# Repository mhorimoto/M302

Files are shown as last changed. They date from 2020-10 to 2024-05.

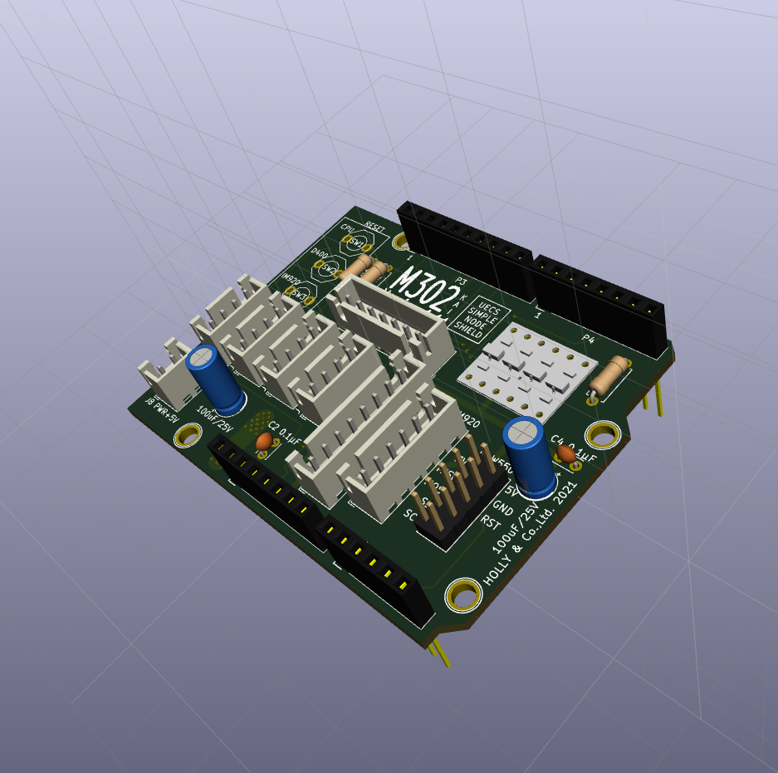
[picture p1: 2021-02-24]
M302kai-3d02.png

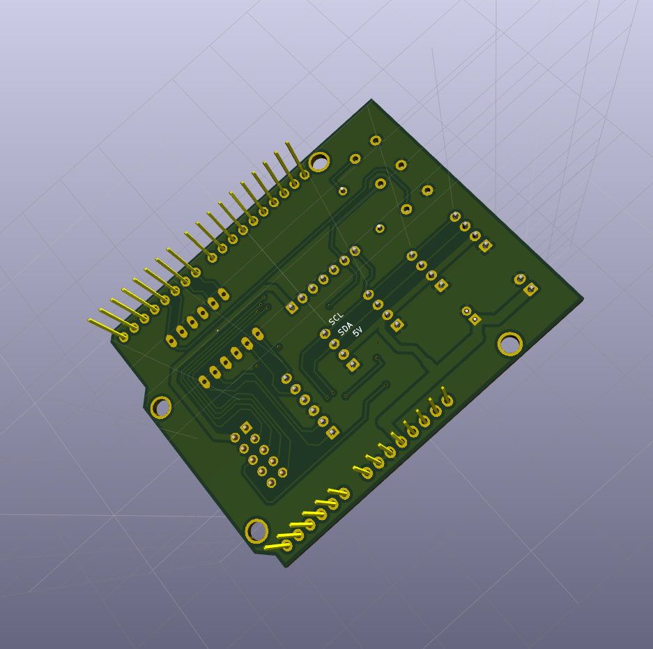
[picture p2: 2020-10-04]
M302-3d06.png

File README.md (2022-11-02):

M302 Arduino UECS SIMPLE NODE Shield 汎用簡易観測ノード
======================================================

# 概要

Arduino UNOのシールドとして UECS で農業環境計測で使用しやすい
センサ類の接続に特化した基板。

## 初版 (1.00)
  commit 2f4df36819d791f5551f218545c303c0058bd9ba
  * I2CとLANとIM920の接続インタフェースを持ったもの。

## 1.10
  * I2CとLANとADC入力とIM920の接続インタフェースを持ったもの。
  * 製作ワークショップなどで使用する用途も考慮。

# Interface仕様

 I2Cは5V仕様。IM920を接続するためだけにレベルコンバータを使用。

## I2C

 便宜的にシルク面にJ1〜J4は名前を記しているが、いずれもI2Cなので、以下のピン配置で同じく使用できる。なお、必要に応じてセンサ側でプルアップをするように。

 | PIN | 意味 |
 |-----|------|
 |  1  | GND  |
 |  2  | +5V  |
 |  3  | SDA  |
 |  4  | SCL  |

 J5はELT社のCO2センサD-400用のインタフェースである。基本的にI2Cであるが、リセット端子を個別に用意している。

 | PIN | 意味 |
 |-----|------|
 |  1  | +5V  |
 |  2  | N/C  |
 |  3  | GND  |
 |  4  | SDA  |
 |  5  | N/C  |
 |  6  | RST  |
 |  7  | SCL  |

## アナログ入力

Arduino UNOの10bits A/Dコンバータ(以降、ADC)を手軽に使用するために4chのコネクタをJ9(ANALOG-IN)として用意している。

 | PIN | 意味 |
 |-----|------|
 |  1  | Ch1  |
 |  2  | GND  |
 |  3  | Ch2  |
 |  4  | GND  |
 |  5  | Ch3  |
 |  6  | GND  |
 |  7  | Ch4  |
 |  8  | GND  |

## IM920接続インタフェース

920MHz伝送用無線通信モジュールIM920を接続するためのシリアルインタフェースを用意している。IM920が3.3V仕様なのでレベルコンバータを実装する。(IM920を使用しない場合にはレベルコンバータは不要)

 | PIN |   意味   |
 |-----|----------|
 |  1  | RESET    |
 |  2  | BUSY     |
 |  3  | GND      |
 |  4  | +3.3V    |
 |  5  | IM920 TX |
 |  6  | IM920 RX |

## LANインタフェース

W5500で一般的に販売されているものが接続出来るように用意している。

 | PIN | 意味  |
 |-----|-------|
 |  1  | +3.3V |
 |  2  | +5V   |
 |  3  | MISO  |
 |  4  | GND   |
 |  5  | MOSI  |
 |  6  | RESET |
 |  7  | SS    |
 |  8  | N/C   |
 |  9  | SCLK  |
 | 10  | N/C   |

# プログラム

スマ農塾に使用したプログラムは別途githubに登録してある。

''git@github.com:mhorimoto/smanou01.git''

それ以外のプログラムは、以下の通り。

## TK01

スマ農塾向けのサンプルプログラムで前述のものよりも古いバージョン

## TPM302K

M302Kの基板の試験をおこなうための試験プログラム。

## TPM302K-NIC

M302KのNIC(W5500)を動作させる試験プログラム

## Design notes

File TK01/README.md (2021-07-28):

スマート農業塾 UECS NODE トレーニングキット01
===========================================

M302KにSHT3xを接続して温度湿度計測を行い、結果をUECS電文で送信する装置。

- Version: V042
- Release: 29-Jul-2021
- Develop: HOLLY&Co.,Ltd.

## 必要なH/W

- Arduino UNO R3 互換機上等。ピン位置など物理形状は本家と同じにする
- M302K HOLLY製シールド基板
- SHT-31 温度湿度センサ
- W5500 NIC
- I2C I/F LCD 1602 (16桁2行)
- AC100/220V to DC5V/1.5A 電源
- プッシュスイッチ
- 電源用トグルスイッチ

## M302Kとの配線

M302KはArduino UNOのシールドとして接続する。

これから書く

## ソフトウェアのインストール

### EEPROMの初期値

この初期値設定は、Arduino UNO 単体で実行する。

MACアドレスやUECSID,ROOM,REGIONなどの位置情報の初期値を設定する。

このプログラムは、lowcore サブディレクトリの配下にある。この lowcore.ino をArduino UNOに最初にインストールして初期値を作成する。  
詳細は、 [lowcore/README.md](lowcore/README.md) を参照の事。

また、初期化の内容は、 [EEPROM_MAP.md](EEPROM_MAP.md) に記されている。

### 主プログラムのインストール

主プログラムは、main サブディレクトリの配下に全て含まれている。
それを Arduino IDE などでコンパイルしてCPUにupload(install)する。

## 使い方

使い方は、取扱説明書を [main/MANUAL.md](main/MANUAL.md) に記すので、そちらを参照する。
まだ書かれていない。

## 著作権

This software is released under the MIT License, see [LICENSE.txt](LICENSE.txt).  
(このソフトウェアは、MITライセンスのもとで公開されている。[LICENSE-ja.txt](LICENSE-ja.txt)を見よ。)

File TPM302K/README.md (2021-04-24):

TPM302K
=======
M302K用検査プログラム

M302Kの基板製造上、接続の正当性を確認する検査プログラム

ArduinoのI/OピンをOutputにして順序立てて接続ピンを点滅させることで、LEDの点滅を見つつ接続を確認する。

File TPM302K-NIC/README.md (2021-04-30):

TPM302K
=======
M302K用検査プログラム W5500 テストプログラム

M302Kの基板製造上、接続の正当性を確認する検査プログラム

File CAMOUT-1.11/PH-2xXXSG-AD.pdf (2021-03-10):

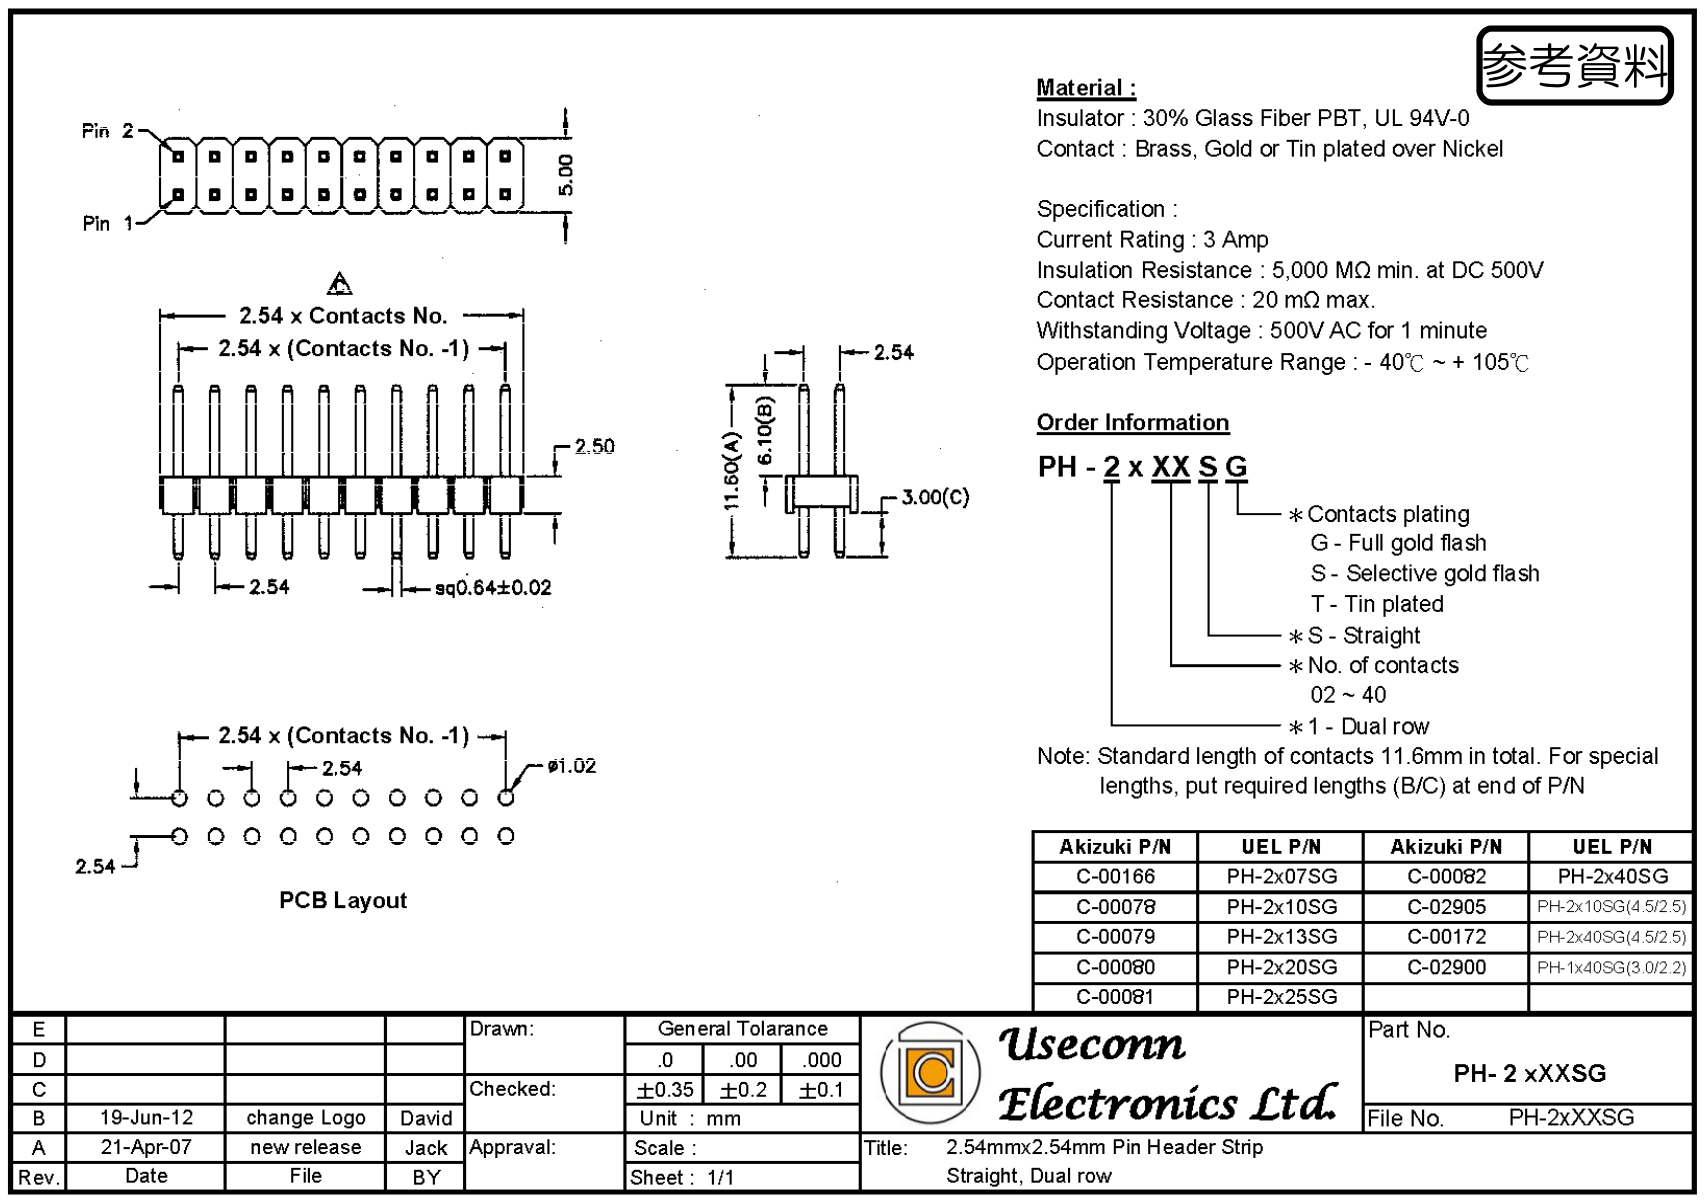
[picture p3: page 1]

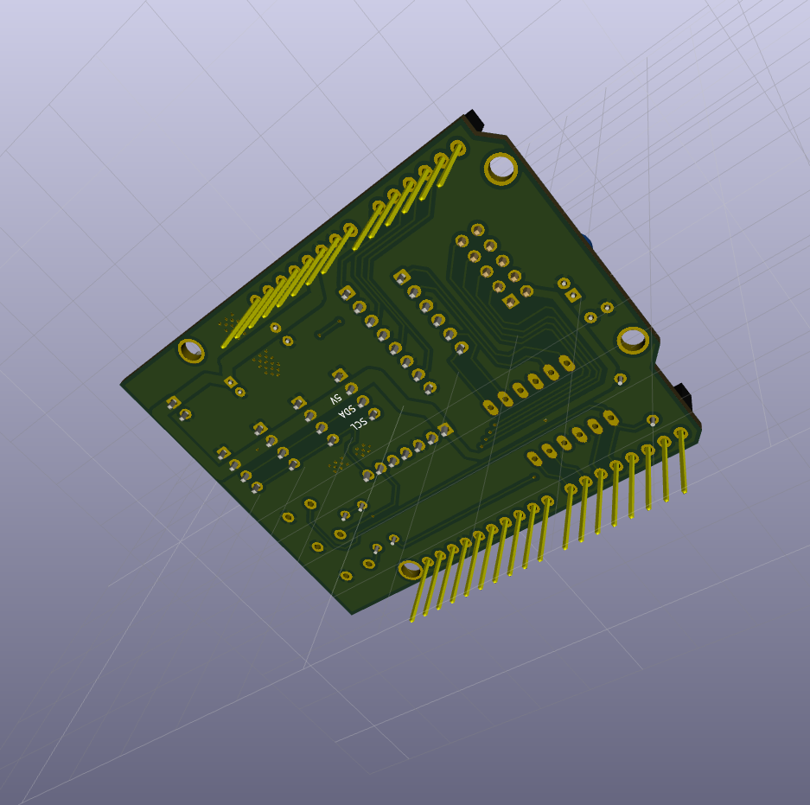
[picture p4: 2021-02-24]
M302kai-3d03.png

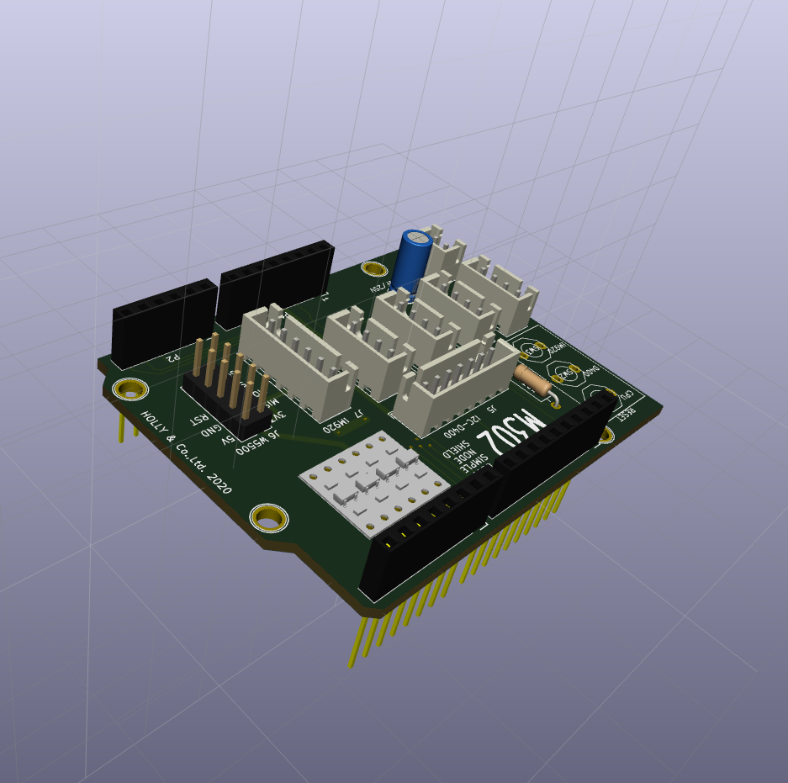
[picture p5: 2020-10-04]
M302-3d07.png

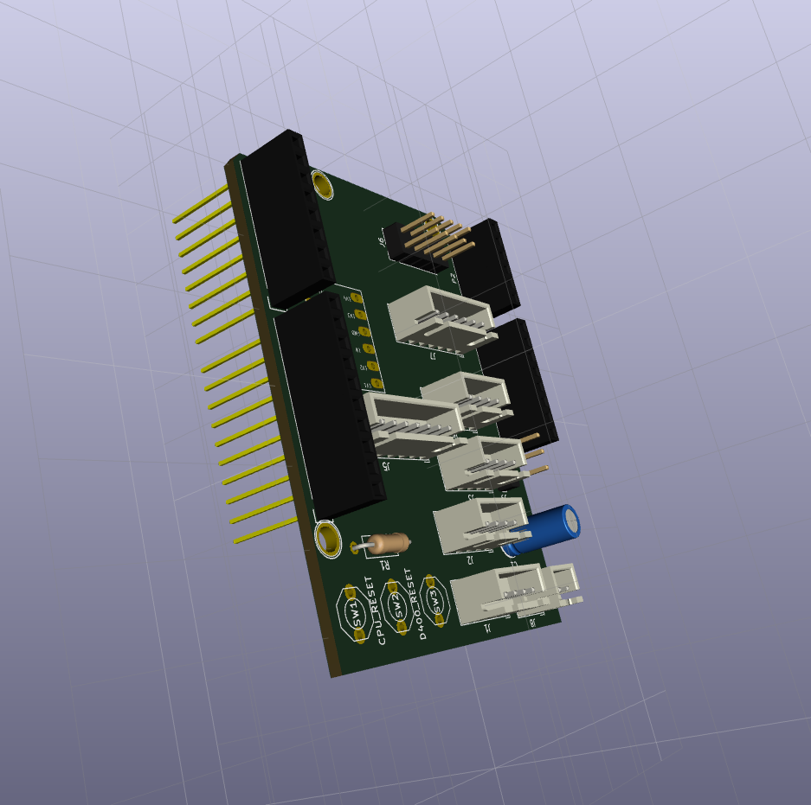
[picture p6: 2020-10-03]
M302-3d02.png

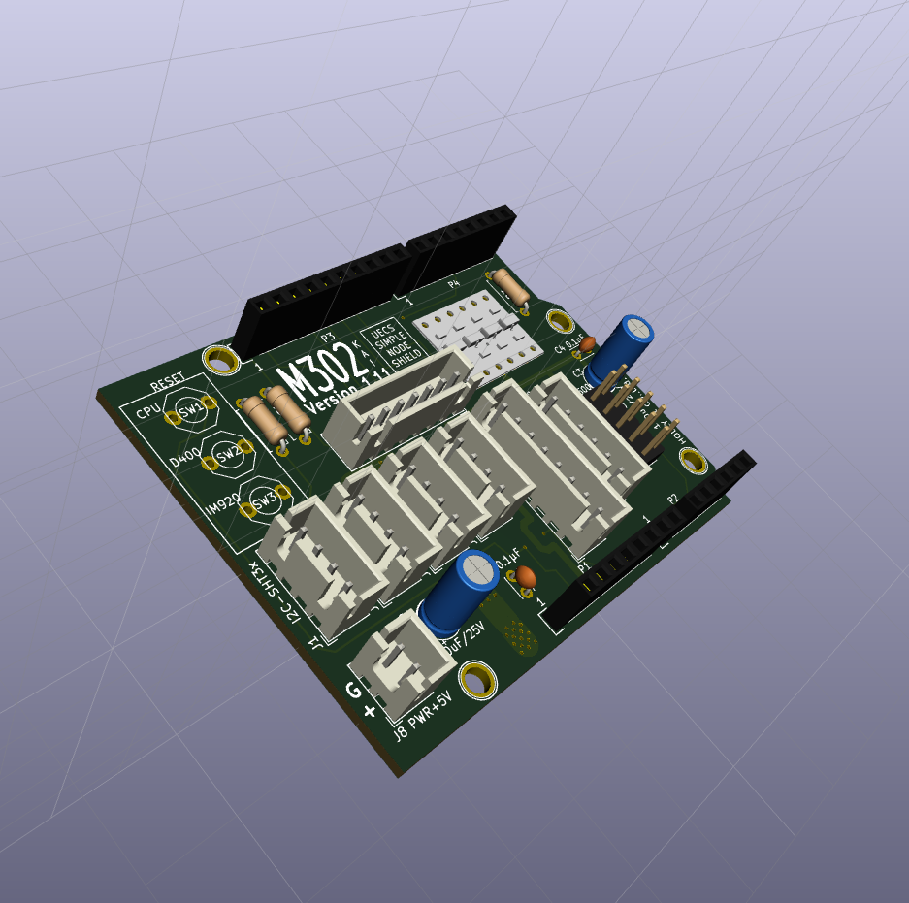
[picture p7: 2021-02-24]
M302kai-3d01.png

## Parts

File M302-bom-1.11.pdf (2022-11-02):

## M302 PARTS LIST

品名 Name | 部品番号 Designator | 個数 Quanity | 値 Value | 秋月品番 | 説明 Description | 部品メーカ Manufacturer | メーカ品番 Manufacturer Part Number
抵抗 | R1 R2 R3 | 3 10kΩ | | R-16103 | | SHIH HAO Electronics | RD16S 10K
コンデンサ | C1 C3 | 2 100uF/25V | | P-03122 | | Rubycon | 25PK100MEFC5X11
コンデンサ | C2 C4 | 2 0.1uF | | P-00090 | | muRata | RPEF11H104Z2P1A01B
XHコネクタ | J1 J2 J3 J4 | 4 | ベース付ポスト・トップ型4P | C-12249 | I2C I/F用 | JST | B4B-XH-A(LF)(SN)
XHコネクタ | J5 | 1 | ベース付ポスト・トップ型7P | C-12252 | D400 I/F用 | JST | B7B-XH-A(LF)(SN)
Pin Header | J6 | 1 | 2.54mmピッチピンヘッダ 2x5 | C-13635 | W5500 I/F用 | Useconn Electronics | PH2X5SG
XHコネクタ | J7 | 1 | ベース付ポスト・トップ型6P | C-12251 | IM920 I/F用 | JST | B6B-XH-A(LF)(SN)
XHコネクタ | J8 | 1 | ベース付ポスト・トップ型2P | C-12247 | POWER用 | JST | B2B-XH-A(LF)(SN)
XHコネクタ | J9 | 1 | ベース付ポスト・トップ型8P | C-12253 | ADC用 | JST | B8B-XH-A(LF)(SN)
Arduino Pin Header | P1 P4 | 2 | ピンソケット 1x8 リード長 10mm | C-04046 | Arduino Long Pin | Useconn Electronics | FH105-1x8SG/RH
Arduino Pin Header | P2 | 1 | ピンソケット 1x6 リード長 10mm | C-04045 | Arduino Long Pin | Useconn Electronics | FH105-1x6SG/RH
Arduino Pin Header | P3 | 1 | ピンソケット 1x10 リード長 10mm | C-07199 | Arduino Long Pin | Useconn Electronics | FH105-1x10SG
タクトスイッチ | SW1 | 1 | タクトスイッチ・1回路1接点・赤 | P-08079 | CPU RESET | Zhejiang Jianfu Electronics | TVDT18-050CR-T
タクトスイッチ | SW2 SW3 | 2 | タクトスイッチ・1回路1接点・白 | P-08080 | I/O RESET | Zhejiang Jianfu Electronics | TVDT18-050CW-T
液晶表示器 | 外部パーツ | 1 LCD 16x2 I2C | | Amazon (https://www.amazon.co.jp/waves-1602-LCD%E6%B6%B2%E6%99%B6-%E3%83%A2%E3%82%B8%E3%83%A5%E3%83%BC%E3%83%AB-Arduino/dp/B07BJ5PW3R) | コネクタ別途 | Waves | LCD-1602-I2C-0X3F
XHハウジング | 外部パーツ | 2 | XHコネクタ ハウジング 4P | C-12257 | LCD,SHT用 | JST | XHP-4
コネクタ用ハウジング | 外部パーツ | 1 | コネクタ用ハウジング4P | C-12153 | LCD用 | Neltron Industrial | 2226A-04
XHコンタクト | 外部パーツ | 1 | XHハウジング用コンタクト入数100個 | C-12265 | | | SXH-001T-P0.6
ケーブル用コネクタ | 外部パーツ | 2 | コンタクト部品入数10個 | C-12160 | | Neltron Industrial | 2226TG
LANモジュール | 外部パーツ | 1 W5500 | | Amazon (https://www.amazon.co.jp/W5500%E3%82%A4%E3%83%BC%E3%82%B5%E3%83%8D%E3%83%83%E3%83%88%E3%82%B7%E3%83%BC%E3%83%AB%E3%83%89lan%E3%83%8D%E3%83%83%E3%83%88%E3%83%A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) | コネクタ別途 | Paialu
コネクタ用ハウジング | 外部パーツ | 2 2x5 | | C-12437 | LANモジュール用 | Chang Enn Co., Ltd. | 254AH-D10
温度湿度センサ | 外部パーツ | 1 SHT35 | | K-15654 | コネクタ別途
コネクタ用ハウジング | 外部パーツ | 1 | コネクタ用ハウジング5P | C-12154 | SHT35用 | Neltron Industrial | 2226A-05
配線用リード線 | 外部パーツ | 適宜 | AWG-28
Arduino UNO R3 | 外部パーツ | 1 Arduino UNO R3 | | | CPU
LCD URL | https://onl.sc/UfVgae6
W5500 URL | https://onl.sc/F9rLdia

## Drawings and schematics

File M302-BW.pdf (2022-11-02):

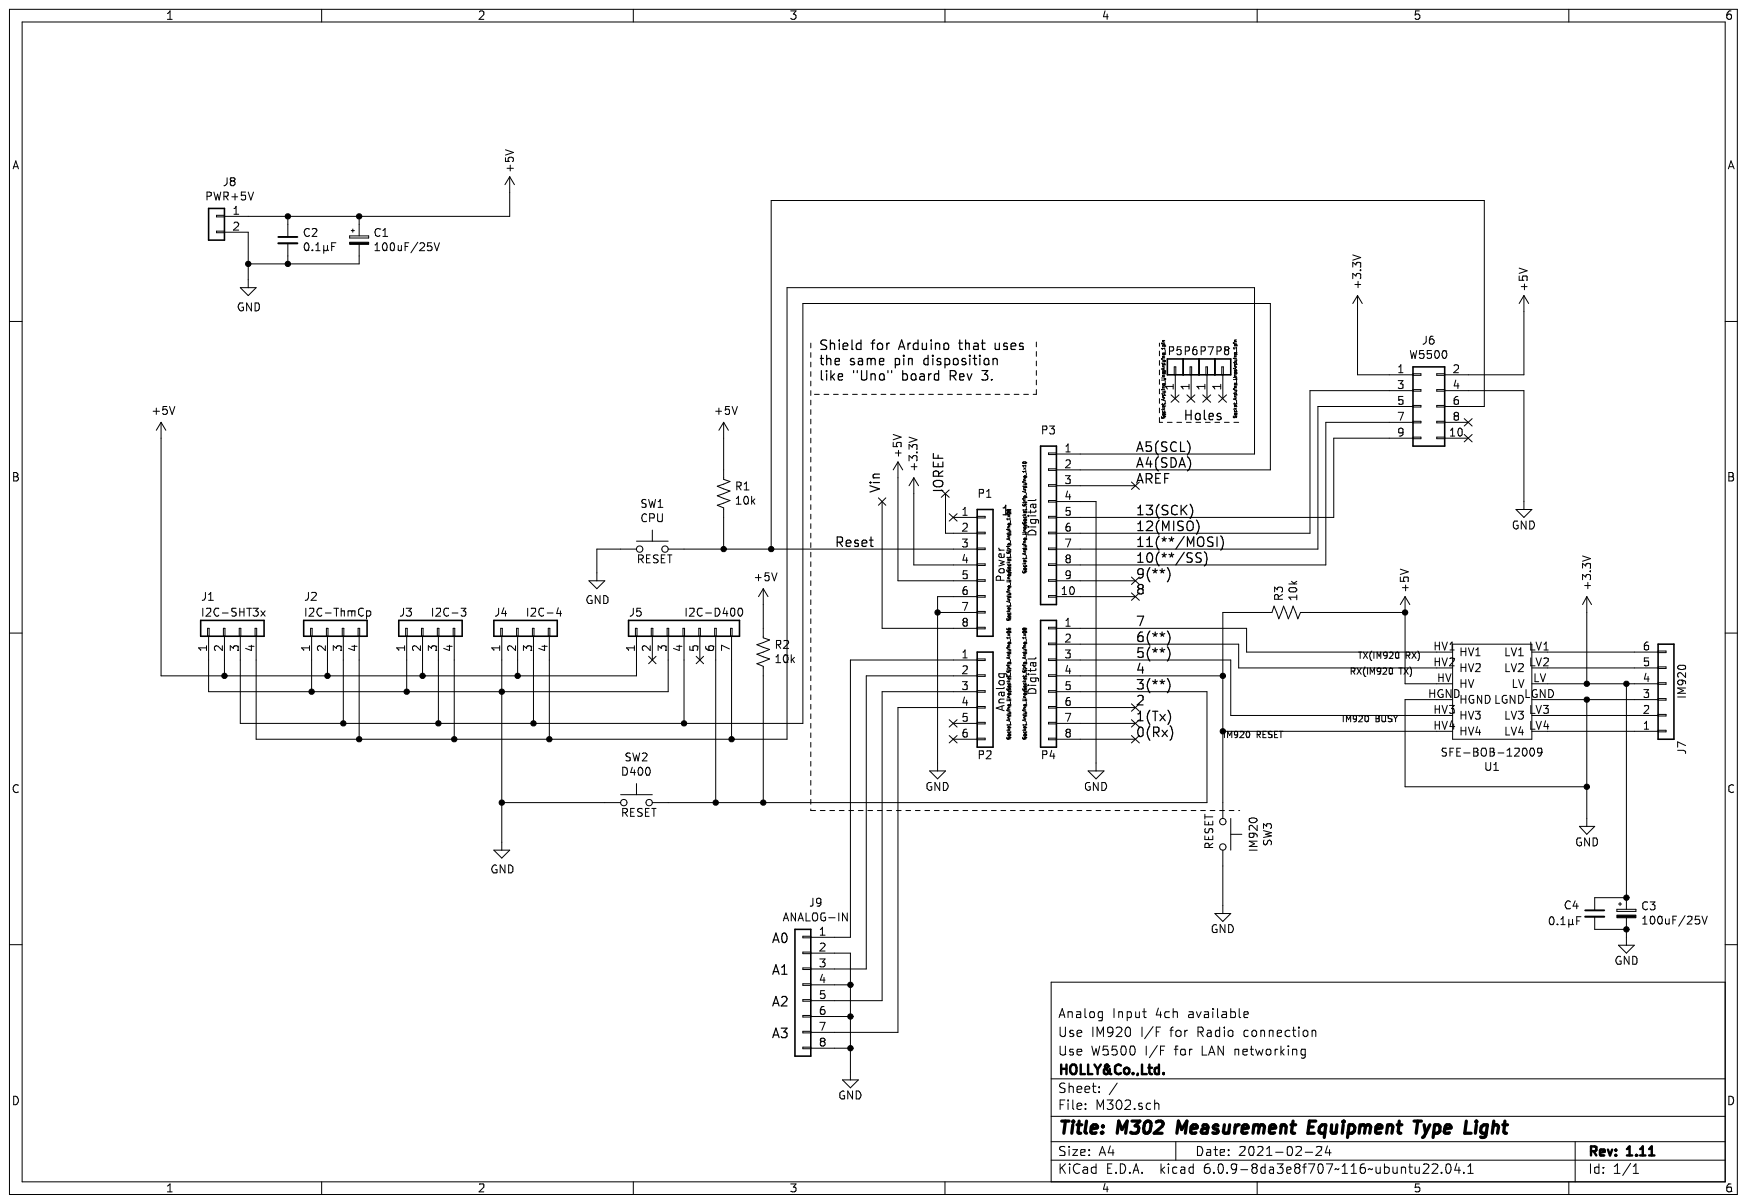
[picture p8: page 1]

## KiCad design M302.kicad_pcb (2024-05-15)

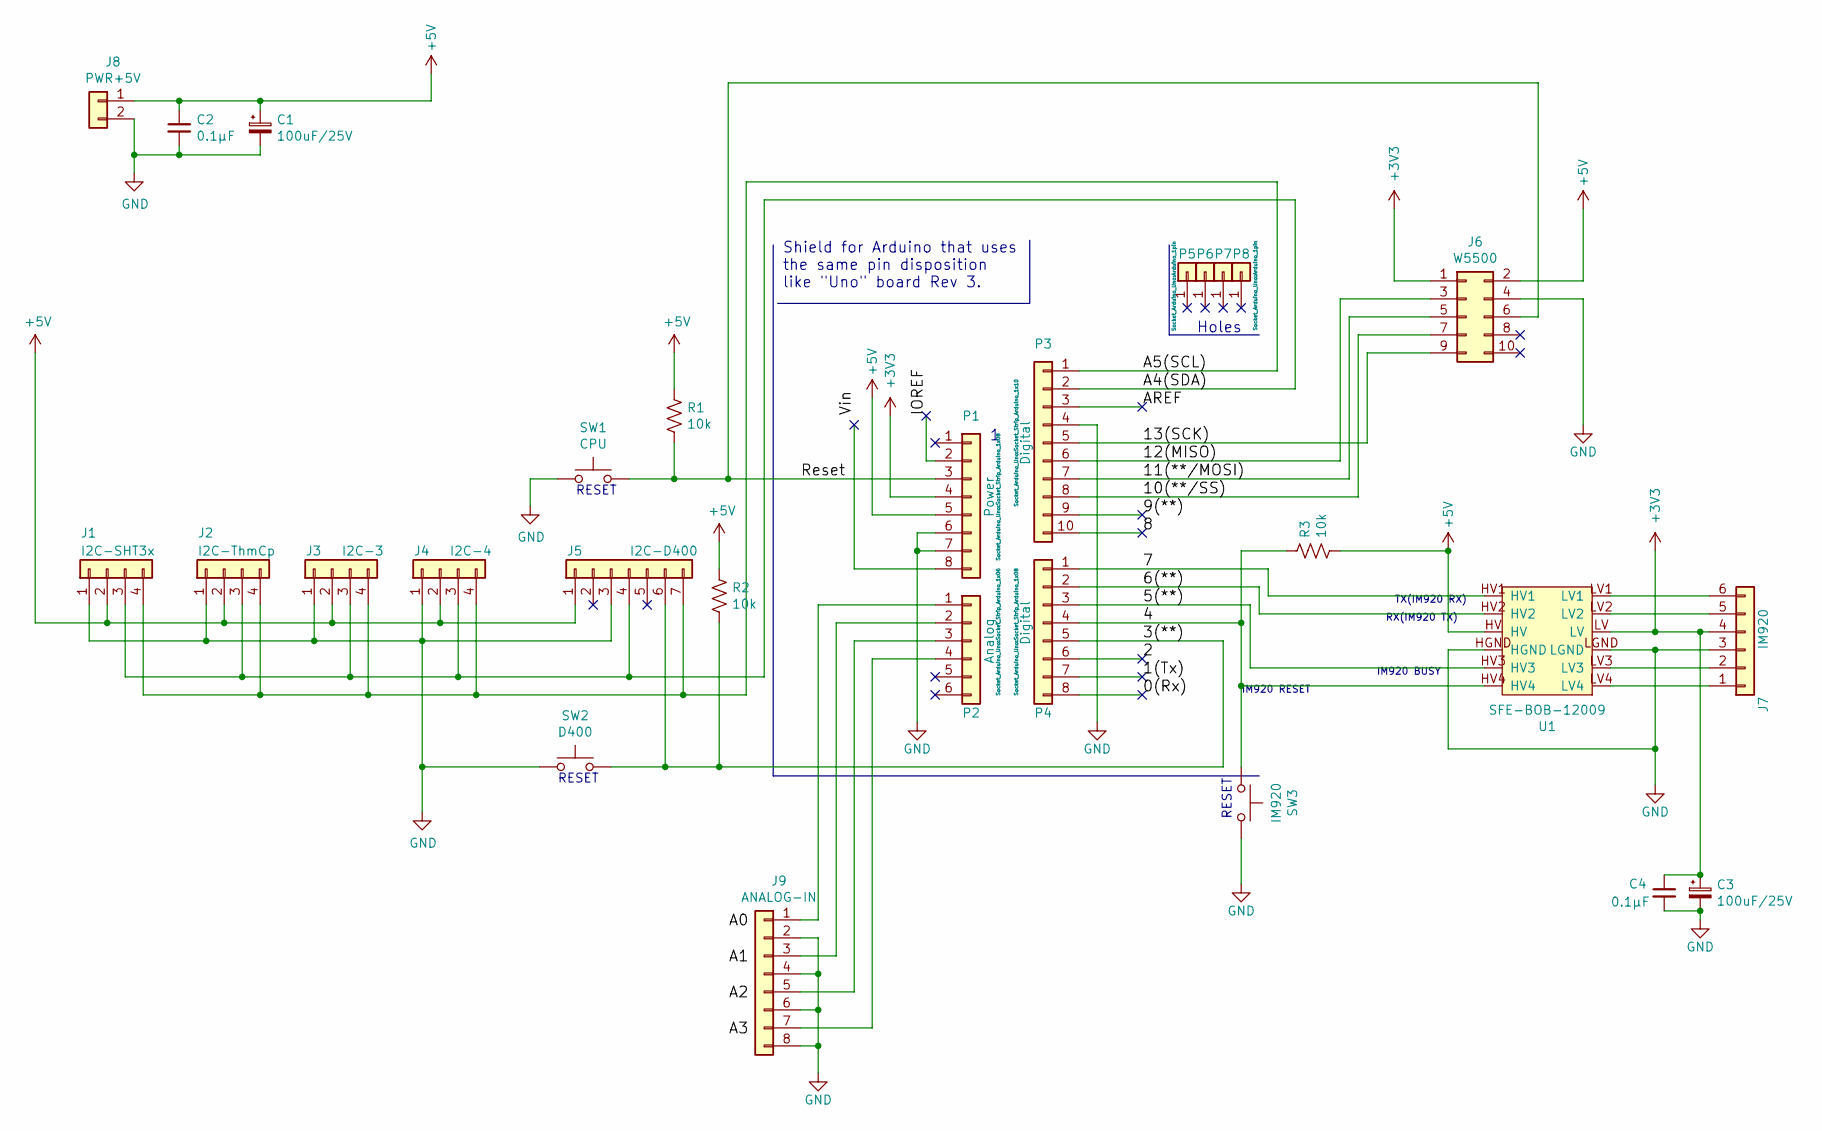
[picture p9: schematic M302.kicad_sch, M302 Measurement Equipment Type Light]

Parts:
C1, C3: 100uF/25V; CP_Radial_D5.0mm_P2.00mm
C2, C4: 0.1μF; C_Disc_D3.0mm_W2.0mm_P2.50mm
J1: I2C-SHT3x; JST_XH_B4B-XH-A_1x04_P2.50mm_Vertical
J2: I2C-ThmCp; JST_XH_B4B-XH-A_1x04_P2.50mm_Vertical
J3: I2C-3; JST_XH_B4B-XH-A_1x04_P2.50mm_Vertical
J4: I2C-4; JST_XH_B4B-XH-A_1x04_P2.50mm_Vertical
J5: I2C-D400; JST_XH_B7B-XH-A_1x07_P2.50mm_Vertical
J6: W5500; PinHeader_2x05_P2.54mm_Vertical
J7: IM920; JST_XH_B6B-XH-A_1x06_P2.50mm_Vertical
J8: PWR+5V; JST_XH_B2B-XH-A_1x02_P2.50mm_Vertical
J9: ANALOG-IN; JST_XH_B8B-XH-A_1x08_P2.50mm_Vertical
P1: Power; Socket_Strip_Arduino_1x08
P2: Analog; Socket_Strip_Arduino_1x06
P3: Digital; Socket_Strip_Arduino_1x10
P4: Digital; Socket_Strip_Arduino_1x08
P5, P6, P7, P8: CONN_01X01; Arduino_1pin
R1, R2, R3: 10k; R_Axial_DIN0207_L6.3mm_D2.5mm_P7.62mm_Horizontal
SW1: CPU; TVDT18-050
SW2: D400; TVDT18-050
SW3: IM920; TVDT18-050
U1: SFE-BOB-12009

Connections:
+3V3: C3.1, C4.1, J6.1, J7.4, P1.4, U1.LV
+5V: C1.1, C2.1, J1.2, J2.2, J3.2, J4.2, J5.1, J6.2, J8.1, P1.5, R1.1, R2.1, R3.2, U1.HV
/0(Rx): P4.8
/1(Tx): P4.7
/2: P4.6
/3(**): J5.6, P4.5, R2.2, SW2.2
/4: P4.4, R3.1, SW3.1, U1.HV4
/5(**): P4.3, U1.HV3
/6(**): P4.2, U1.HV2
/7: P4.1, U1.HV1
/8: P3.10
/9(**): P3.9
/10(**/SS): J6.7, P3.8
/11(**/MOSI): J6.5, P3.7
/12(MISO): J6.3, P3.6
/13(SCK): J6.9, P3.5
/A4(SDA): J1.3, J2.3, J3.3, J4.3, J5.4, P3.2
/A5(SCL): J1.4, J2.4, J3.4, J4.4, J5.7, P3.1
/AREF: P3.3
/IOREF: P1.2
/Reset: J6.6, P1.3, R1.2, SW1.2
GND: C1.2, C2.2, C3.2, C4.2, J1.1, J2.1, J3.1, J4.1, J5.3, J6.4, J7.3, J8.2, J9.2, J9.4, J9.6, J9.8, P1.6, P1.7, P3.4, SW1.1, SW2.1, SW3.2, U1.HGND, U1.LGND
unnamed: J7.1, U1.LV4
unnamed: J7.2, U1.LV3
unnamed: J7.5, U1.LV2
unnamed: J7.6, U1.LV1
unnamed: J9.1, P2.1
unnamed: J9.3, P2.2
unnamed: J9.5, P2.3
unnamed: J9.7, P2.4

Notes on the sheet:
RESET
RX(IM920 TX)
Shield for Arduino that uses the same pin disposition like "Uno" board Rev 3.
Holes
IM920 BUSY
TX(IM920 RX)
IM920 RESET

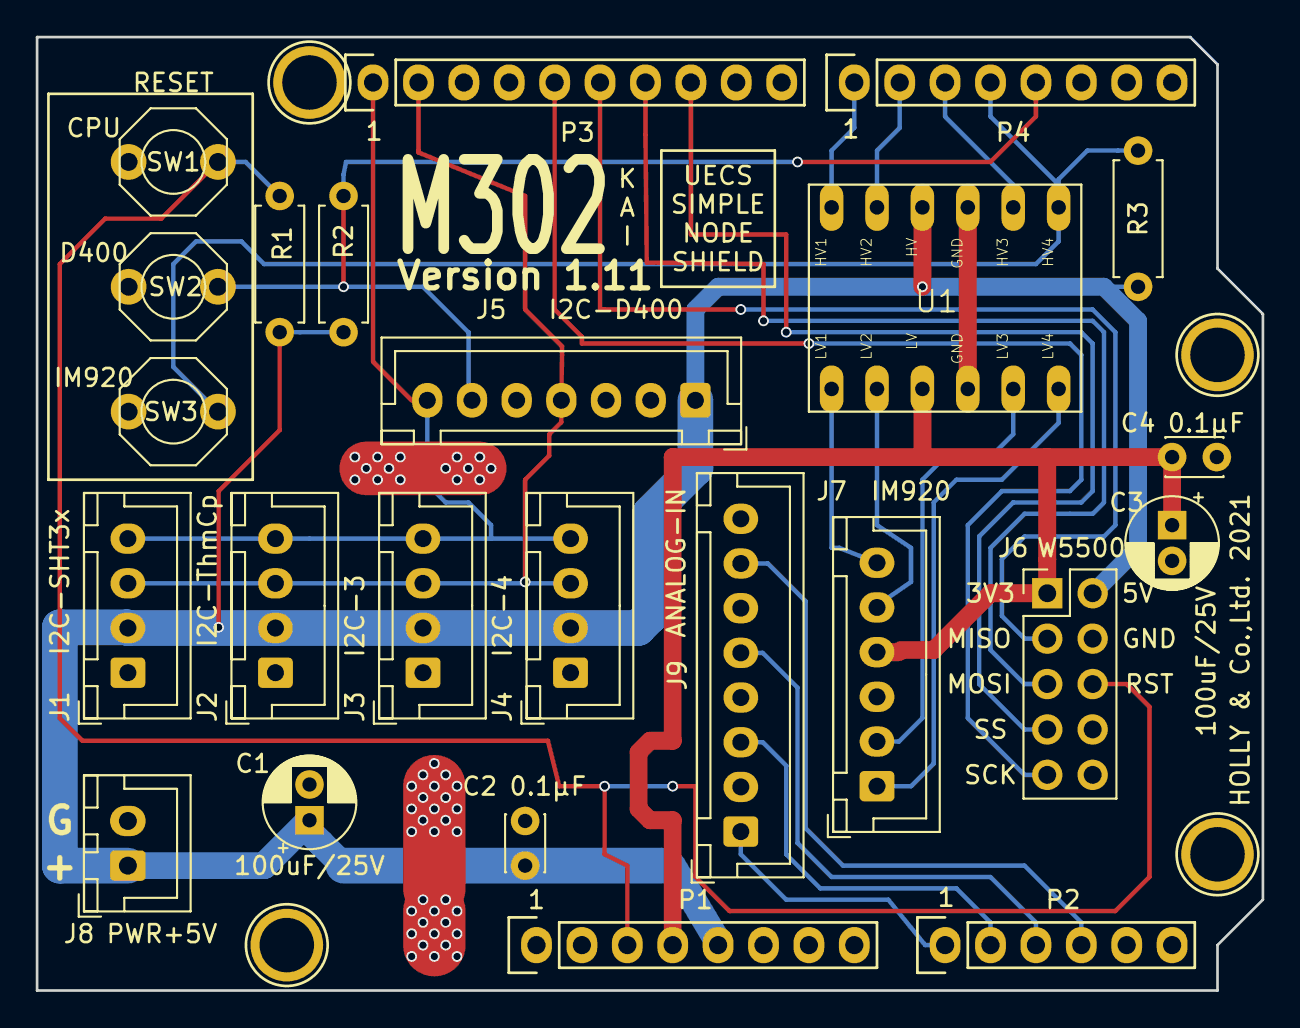
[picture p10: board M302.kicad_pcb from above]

Board: 2 copper layers, 68.6 x 53.3 mm, 28 parts (0 on the bottom side), 23 nets.

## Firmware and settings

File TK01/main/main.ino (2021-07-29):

///////////////////////////////////////////////////////////////////
// M302K-TK01
//  MIT License
//  Copyright (c) 2021 Masafumi Horimoto
//  Release on 29-July-2021
//  https://github.com/mhorimoto/M302.git
///////////////////////////////////////////////////////////////////


#include <stdio.h>
#include <SPI.h>
#include <Ethernet2.h>
#include <EthernetUdp2.h> // UDP library from: bjoern@cs.stanford.edu 12/30/2008
#include <avr/pgmspace.h>
#include <avr/wdt.h>
#include <EEPROM.h>
#include <LiquidCrystal_I2C.h>
#include <Wire.h>
#include <Adafruit_I2CDevice.h>
#include <Adafruit_I2CRegister.h>
#include "Adafruit_SHT31.h"

uint8_t mcusr_mirror __attribute__ ((section (".noinit")));
void get_mcusr(void)	 \
  __attribute__((naked)) \
  __attribute__((section(".init3")));
void get_mcusr(void) {
  mcusr_mirror = MCUSR;
  MCUSR = 0;
  wdt_disable();
}

#define  UECS_PORT  16520
#define  pUECSID      0
#define  pMACADDR     6
#define  pINAIRTEMP  16
#define  pINAIRHUMID 33
#define  pINILLUMI   51
#define  pCND        0x43
#define  delayMillis 5000UL // 5sec

const char VERSION[16] PROGMEM = "\xbd\xcf\xc9\xb3\xbc\xde\xad\xb8 V042";

char uecsid[6], uecstext[180],strIP[16],linebuf[80];
byte lineptr = 0;
int  sht31addr = 0x44;  // Default SHT31 I2C Address
unsigned long cndVal;   // CCM cnd Value
bool enableHeater = false;
char api[] = "api.smart-agri.jp";

/////////////////////////////////////
// Hardware Define
/////////////////////////////////////

LiquidCrystal_I2C lcd(0x27,16,2);  // set the LCD address to 0x27 for a 16 chars and 2 line display
char lcdtext[5][17];

Adafruit_SHT31 sht31 = Adafruit_SHT31();

byte macaddr[6];
IPAddress localIP,broadcastIP,subnetmaskIP,remoteIP;
EthernetUDP Udp16520; //,Udp16529;
EthernetClient EthClient; // GIS Client

volatile int period1sec = 0;
volatile int period10sec = 0;
volatile int period60sec = 0;

void setup(void) {
  int i;
  const char *ids PROGMEM = "%s:%02X%02X%02X%02X%02X%02X";
  extern void lcdout(int,int,int);

  cndVal = 0L;    // Reset cnd value
  lcd.init();
  lcd.backlight();
  configure_wdt();
  pinMode(2,INPUT_PULLUP);
  EEPROM.get(pUECSID,uecsid);
  EEPROM.get(pMACADDR,macaddr);
  for(i=0;i<16;i++) {
    lcdtext[0][i] = pgm_read_byte(&(VERSION[i]));
  }
  lcdtext[0][i] = 0;
  sprintf(lcdtext[1],ids,"ID",
	  uecsid[0],uecsid[1],uecsid[2],uecsid[3],uecsid[4],uecsid[5]);
  lcdout(0,1,1);
  Serial.begin(115200);
  Serial.println(lcdtext[0]);
  Serial.println("ST1"); // SHT31 test
  if (! sht31.begin(sht31addr)) {   // Set to 0x45 for alternate i2c addr
    Serial.println(F("ET1"));       // NO SHT31 at 0x44
    for(i=0;i<10;i++) {
      delay(100);
      if (sht31.begin(sht31addr)) {
	Serial.println(F("ST2"));    // SHT31 at 0x44
	break;
      }
    }
    if (i==10) {
      Serial.println(F("ET2")); // NOT FOUND SHT31 SKIP
      strcpy(lcdtext[3],"NO SHT31 SKIP   ");
      lcdout(0,3,0);
      sht31addr = 0;
      cndVal |= 0x01000000;   // cnd:Alert=1
    }
  }
  delay(500);
  Ethernet.init(10);
  if (Ethernet.begin(macaddr)==0) {
    sprintf(lcdtext[1],"NFL");
  } else {
    localIP = Ethernet.localIP();
    subnetmaskIP = Ethernet.subnetMask();
    for(i=0;i<4;i++) {
      broadcastIP[i] = ~subnetmaskIP[i]|localIP[i];
    }
    sprintf(lcdtext[2],ids,"HW",
	    macaddr[0],macaddr[1],macaddr[2],macaddr[3],macaddr[4],macaddr[5]);
    sprintf(strIP,"%d.%d.%d.%d",localIP[0],localIP[1],localIP[2],localIP[3]);
    sprintf(lcdtext[3],"%s",strIP);
    //    sprintf(lcdtext[0],"%d.%d.%d.%d",broadcastIP[0],broadcastIP[1],broadcastIP[2],broadcastIP[3]);
    lcdout(2,3,1);
    Udp16520.begin(16520);
  }
  wdt_reset();
  cndVal |= 0x00000001;  // Setup completed
  delay(1000);
  //
  // Setup Timer1 Interrupt
  //
  TCCR1A  = 0;
  TCCR1B  = 0;
  TCCR1B |= (1 << WGM12) | (1 << CS12) | (1 << CS10);  //CTCmode //prescaler to 1024
  OCR1A   = 15625-1;
  TIMSK1 |= (1 << OCIE1A);
  //
  // Opening Messages
  //
  //  Serial.println(lcdtext[1]);
  //  Serial.println(lcdtext[2]);
  //  Serial.println(lcdtext[3]);
  //  Serial.println(lcdtext[0]);
}

/////////////////////////////////
// Reset Function goto Address 0
/////////////////////////////////
void(*resetFunc)(void) = 0;

/////////////////////////////////
void loop() {
  static int k=0;
  int i,ia,ta,tb;
  byte room,region,priority,interval;
  int  order;
  int  inchar ;
  float ther,humi;
  //  static byte s = 0;
  char name[10],dname[11],val[6];
  extern void lcdout(int,int,int);
  extern int setParam(char *);
  extern void dumpLowCore(void);
  
  const char *xmlDT PROGMEM = "<?xml version=\"1.0\"?><UECS ver=\"1.00-E10\"><DATA type=\"%s.mIC\" room=\"%d\" region=\"%d\" order=\"%d\" priority=\"%d\">%s</DATA><IP>%s</IP></UECS>";
  //  const char *thdisp PROGMEM = "%3d %3d %3d %3d";
  const char *ids PROGMEM = "%s:%02X%02X%02X%02X%02X%02X";
  
  //if (EthClient.available()) {
  //    char c = EthClient.read();
  //    Serial.write(c);
  //  }

   wdt_reset();
//   //////////////////////////////////////////////////////////////
//   if ( Serial.available() > 0 ) {
//     inchar = Serial.read();
//     if (( inchar == 0x13 )||( inchar == 0x0a)||( lineptr > 63)) {
//       if ( !strcmp(linebuf,"d") ) {
// 	dumpLowCore();
//       } else if ( !strncmp(linebuf,"s ",2 )) {
// 	if ( setParam(linebuf) != 0 ) {
// 	  Serial.println(F("BAD"));
// 	} else {
// 	  Serial.println(F("OK"));
// 	}
//       } else if ( !strcmp(linebuf,"reset" )) {
// 	resetFunc();
//       } else {
// 	Serial.print(linebuf);
// 	Serial.println(F(" ?"));
//       }
//       lineptr = 0;
//     } else {
//       linebuf[lineptr] = (char)inchar;
//       lineptr++;
//     }
//     linebuf[lineptr] = (char)NULL;
//   }
  // 10 sec interval
  if (period10sec==1) {
    wdt_reset();
    period10sec = 0;
    if (sht31addr>0) {
      //      ther = sht31.readTemperature();
      ia = pINAIRTEMP;
      getSHTdata(&val[0],pINAIRTEMP,0);  // 整数型にしない
      //     Serial.println(val);
      sprintf(linebuf,"T=%sC",val);
      uecsSendData(pINAIRTEMP,xmlDT,val);
      getSHTdata(&val[0],pINAIRHUMID,0);  // 整数型
      uecsSendData(pINAIRHUMID,xmlDT,val);
      sprintf(lcdtext[4],"%s H=%s%%",linebuf,val);
    } else {
      strcpy(lcdtext[4],("NO SHT SENSOR"));
    }
    k++;
    if (k>3) k=0;
    lcdout(k,4,1);
  }
  // 1 min interval
  if (period60sec==1) {
    period60sec = 0;
    wdt_reset();
    if (sht31addr>0) {
      getSHTdata(&val[0],pINAIRTEMP,1); // 小数点下1桁の整数型
      ia = gisSendData(pINAIRTEMP,16,val);
      switch(ia) {
      case 0:
	cndVal &= 0xffcffeff; // 
	break;
      case 1:
	cndVal |= 0x00100100; // Not connect to Server
	break;
      case 2:
	cndVal |= 0x00200100; // Server response timeout
	break;
      }
      wdt_reset();
      getSHTdata(&val[0],pINAIRHUMID,0); // 整数型
      ia = gisSendData(pINAIRHUMID,17,val);
      switch(ia) {
      case 0:
	cndVal &= 0xffcffdff; // 
	break;
      case 1:
	cndVal |= 0x00100200; // Not connect to Server
	break;
      case 2:
	cndVal |= 0x00200200; // Server response timeout
	break;
      }
      cndVal &= 0xffffff0f;  // Reset maintain code
      ia = Ethernet.maintain();
      if (ia!=0) {
	cndVal |= ((ia << 4) & 0xf0);
      }
    }
  }
  // 1 sec interval
  if (period1sec==1) {
    period1sec = 0;
    ia = pCND;
    sprintf(val,"%u",cndVal);
    uecsSendData(ia,xmlDT,val);
    cndVal &= 0xfffffffe;            // Clear setup completed flag
  }
  wdt_reset();
}

ISR(TIMER1_COMPA_vect) {
  static byte cnt10,cnt60;
  cnt10++;
  cnt60++;
  period1sec = 1;
  if (cnt10 >= 10) {
    cnt10 = 0;
    period10sec = 1;
  }
  if (cnt60 >= 60) {
    cnt60 = 0;
    period60sec = 1;
  }
}


void configure_wdt(void) {
  cli();                           // disable interrupts for changing the registers
  MCUSR = 0;                       // reset status register flags
                                   // Put timer in interrupt-only mode:
  WDTCSR |= 0b00011000;            // Set WDCE (5th from left) and WDE (4th from left) to enter config mode,
                                   // using bitwise OR assignment (leaves other bits unchanged).
  WDTCSR =  0b00001000 | 0b100001; // clr WDIE: interrupt enabled
                                   // set WDE: reset disabled
                                   // and set delay interval (right side of bar) to 8 seconds
  sei();                           // re-enable interrupts
                                   // reminder of the definitions for the time before firing
                                   // delay interval patterns:
                                   //  16 ms:     0b000000
                                   //  500 ms:    0b000101
                                   //  1 second:  0b000110
                                   //  2 seconds: 0b000111
                                   //  4 seconds: 0b100000
                                   //  8 seconds: 0b100001
}

void uecsSendData(int a,char *xmlDT,char *val) {
  byte room,region,priority,interval;
  int  order,i;
  char name[10],dname[11]; // ,val[6];
  EEPROM.get(a+0x01,room);
  EEPROM.get(a+0x02,region);
  EEPROM.get(a+0x03,order);
  EEPROM.get(a+0x05,priority);
  EEPROM.get(a+0x06,interval);
  EEPROM.get(a+0x07,name);
  for(i=0;i<10;i++) {
    dname[i] = name[i];
    if (name[i]==NULL) break;
  }
  dname[i] = NULL;
  sprintf(uecstext,xmlDT,dname,room,region,order,priority,val,strIP);
  Udp16520.beginPacket(broadcastIP,16520);
  Udp16520.write(uecstext);
  Udp16520.endPacket();
}

byte gisSendData(int a,int sk,char *val) {
  int connectLoop = 0;
  int inChar;
  char headline[20];
  const char *gisDT PROGMEM = "M=%02X%02X.%02X%02X.%02X%02X&I=%d&P=%d&V=%s&RM=%d&RE=%d&OD=%d&PR=%d&TP=%s.mIC";
  byte room,region,priority,interval;
  int  order,i;
  char name[10],dname[11];

  lcd.setCursor(15,1);
  lcd.print("W");
  EEPROM.get(a+0x01,room);
  EEPROM.get(a+0x02,region);
  EEPROM.get(a+0x03,order);
  EEPROM.get(a+0x05,priority);
  EEPROM.get(a+0x06,interval);
  EEPROM.get(a+0x07,name);
  for(i=0;i<10;i++) {
    dname[i] = name[i];
    if (name[i]==NULL) break;
  }
  dname[i] = NULL;

  wdt_reset();
  sprintf(linebuf,gisDT,macaddr[0],macaddr[1],macaddr[2],macaddr[3],macaddr[4],macaddr[5],
	  order,sk,val,room,region,order,priority,dname);
  //  Serial.println(linebuf);
  EthClient.stop();
  if (EthClient.connect(api,80)) {
    EthClient.println(F("POST /farmem/rx/rxdata.php HTTP/1.1"));
    EthClient.println(F("Host: api.smart-agri.jp"));
    EthClient.println(F("Connection: close\r\nContent-Type: application/x-www-form-urlencoded"));
    sprintf(headline,"Content-Length: %u\r\n",strlen(linebuf));
    EthClient.println(headline);
    EthClient.print(linebuf);
  } else {
    Serial.println(F("SISE"));
    lcd.setCursor(15,1);
    lcd.print("E");
    return 1;
  }
  while(EthClient.connected()) {
    wdt_reset();
    while(EthClient.available()) {
      inChar = EthClient.read();
      //      Serial.write(inChar);
      connectLoop = 0;
    }
    delay(1);
    connectLoop++;
    wdt_reset();
    if(connectLoop > delayMillis) {
      lcd.setCursor(15,1);
      lcd.print("T");
      EthClient.stop();
      return 2;
    }
  }
  EthClient.stop();
  lcd.setCursor(15,1);
  lcd.print(" ");
  return 0;
}

void getSHTdata(char *v,int a,int f) {
  float fv;
  int ta,tb;
  switch(a) {
  case pINAIRTEMP:
    fv = sht31.readTemperature();
    if (f==0) {
      ta = (int)fv;
      tb = round((double)((fv-ta)*10));
      if (tb>=10.0) {
	ta++;
	tb-=10;
      }
      sprintf(v,"%d.%01d",ta,tb);
    } else {
      ta = round(fv*pow(10.0,f)) ; // f=2ならば、100倍する
      sprintf(v,"%d",ta);
    }
    break;
  case pINAIRHUMID:
    fv = sht31.readHumidity();
    sprintf(v,"%d",(int)fv);
    break;
  }
}

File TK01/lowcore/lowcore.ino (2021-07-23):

///////////////////////////////////////////////////////
// -*- mode : C++ -*-
// EEPROM editor for M302K TK01
//
//[概要]
//  スマ農塾で使用するM302K TK01のEEPROM領域の
//                                初期化を行うプログラム
//
///////////////////////////////////////////////////////

#include <stdio.h>
#include <EEPROM.h>

void setup(void) {
  unsigned int i,j,r,a,u;
  byte t,room;
  char c,name[8],z[4];
  byte uecsid[6]={0x10,0x10,0x0c,0x00,0x00,0x0A},uecsrd[6];
  byte macadd[6]={0x02,0xa2,0x73,0x0A,0xff,0xff};
  byte data[] ={
    'T',1,1,1,0,15,10,'I','n','A','i','r','T','e','m','p',0,
    'H',1,1,1,0,15,10,'I','n','A','i','r','H','u','m','i','d',0,
    'I',1,1,1,0,15,10,'I','n','I','l','l','u','m','i',0,
    'c',1,1,1,0,29, 1,'c','n','d',0
  };
  Serial.begin(115200);
  Serial.println("EEPROM SETTING for TK01 VER 0.03");
  pinMode(3,INPUT_PULLUP);   // D400 RESET BUTTON
  delay(100);
  EEPROM.get(0x0,uecsrd);
  for(i=0;i<6;i++) {
    if (uecsrd[i]!=uecsid[i]) {
      r = 1;  // 書き込む
      break;
    } else {
      r = 0;  // 書き込まない
    }
  }
  if (digitalRead(3)==LOW) {
    r = 1;
  }
  if (r==0) { // 書き込み済ならば表示だけを行って終了
    Serial.println("FINE DID NOT WRITE");
    Serial.println("HEXDATA:");
    for(j=0;j<5;j++) {
      sprintf(z,"0x%03X:",j*0x10);
      Serial.print(z);
      for(i=0;i<16;i++) {
	sprintf(z,"%02X",EEPROM.read(i+(j*0x10)));
	Serial.print(z);
	if (i<15) Serial.print(",");
      }
      Serial.println();
    }
    Serial.print("Are You modify this ? ");
    u = 0;
    while(u==0) {
      if (Serial.available()>0) {
	u = Serial.read();
	if (u!='y') {
	  Serial.println();
	  Serial.println("END");
	  Serial.end();
	  while(1) {
	    u = 0;    // PROGRAM END HERE
	  }
	}
      }
    }
  }
  //
  // DATA WRITE START HERE
  //
  EEPROM.put(0x0,uecsid);
  Serial.println("WRITE DONE");
  Serial.print("UECSID:");
  for(i=0;i<6;i++) {
    Serial.print(EEPROM.read(i),HEX);
    Serial.print(",");
  }
  Serial.println("");
  Serial.print("ENTER SERIAL NUMBER:");
  r = 0;
  j = 0;
  while(r!=0x0d) {
    if (Serial.available()>0) {
      r =Serial.read();
      if ((r>=0x30)&&(r<=0x39)) {
	r -= 0x30;
	Serial.print(r,DEC);
	j *= 10;
	j += r;
      }
    }
  }
  Serial.println("");
  Serial.print("DATA:");Serial.println(j,DEC);
  t = (j >> 8) & 0xff;
  macadd[4] = t;
  macadd[5] = (byte)(j & 0xff);
  Serial.print("MAC ADDRESS=");
  for(i=0;i<6;i++) {
    Serial.print(macadd[i],HEX);
    if (i<5) Serial.print(":");
  }
  Serial.println(); 
  EEPROM.put(0x6,macadd);
  Serial.print("MAC=");
  for(i=0;i<6;i++) {
    Serial.print(EEPROM.read(6+i),HEX);
    if (i<5) Serial.print(":");
  }
  room = (macadd[5]+30)&0x7f;
  data[0x01] = room ; // InAirTemp
  data[0x12] = room ; // InAirHumid
  data[0x24] = room ; // InIllumi
  data[0x34] = room ; // cnd
  Serial.println("");
  EEPROM.put(0x10,data);
  Serial.println("DATA WROTE");
  
  Serial.println("HEXDATA:");
  for(j=0;j<5;j++) {
    for(i=0;i<16;i++) {
      Serial.print(EEPROM.read(i+(j*0x10)),HEX);
      if (i<15) Serial.print(",");
    }
    Serial.println();
  }
  Serial.end();
}


void loop(void) {
}

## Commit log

2020-10-03 とりあえず
    [M302.kicad_pcb, M302.sch]
2020-10-03 VSWは不要なので外す
    [M302.kicad_pcb, M302.sch]
2020-10-04 現在基板確認中
    [M302-B_Cu.gbr, M302-B_Mask.gbr, M302-B_SilkS.gbr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]
2021-01-06 1st release
    [M302-B_Cu.gbr, M302-B_Mask.gbr, M302-B_SilkS.gbr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]
2021-01-14 sch: 1.10 PullUp抵抗とアナログインプットを増やす
    [M302.kicad_pcb, M302.sch]
2021-01-15 M302改 v1.10 PCB作業途中
    [M302.kicad_pcb, M302.sch]
2021-01-15 pcb: M302改 v1.10 PCB作業一旦終了
    [M302.kicad_pcb]
2021-01-15 pcb: v1.10 3D画像作成。もう少しシルクとドキュメントを追加予定
2021-02-24 sche: board: docs:
    [M302.kicad_pcb, M302.sch]
2021-02-24 rel: 1.10
    [M302-B_Cu.gbr, M302-B_Mask.gbr, M302-B_SilkS.gbr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]
2021-02-24 rel: 1.11 コンデンサ3Dモデル変更
    [M302-B_Cu.gbr, M302-B_Mask.gbr, M302-B_SilkS.gbr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]
2021-02-24 sche: Rev変更1.11へ
    [M302.sch]
2021-02-26 docs: 回路図PDF出力
2021-03-10 1.11 PCBgogo向けにBOM関連資料準備
    [B67819ASC16-1-部品調達-1.ods, M302-bom-1.11.ods, M302-bom-1.11.xlsx]
2021-04-24 feat: テストプログラム追加
    [B67819ASC16-1-部品調達-1.xlsx]
2021-04-26 docs: 動画制作
2021-04-30 test: W5500テストプログラム追加
2021-06-20 TK01: トレーニングキット用プログラム作成開始
2021-06-21 feat: lowcore初期化完成
2021-06-21 必要ファイルのコピーまで終了
2021-07-05 feat: 一応センサ無しでloop動作まで完了
2021-07-20 feat:EEPROMのデータ配置を変更する。MACアドレスの最下位を+30してROOMに割り付ける。
2021-07-23 feat: HTTPを追加。GETで実験まで
2021-07-25 feat: V040 だいたい出来た。なぜか110分でrebootする。
2021-07-28 feat,docs: V042リリース初版。ドキュメントはこれから。
2021-07-29 docs: Releases日を修正。
2022-07-05 KiCAD new version
2022-07-05 docs:ソフトウェアの説明を追加
2022-11-01 回路図のPDF出力の追加
2022-11-01 docs: add BOM
    [M302-bom-1.11.ods]
2023-04-22 sche: KiCAD 7.0対応
    [M302.kicad_pcb, M302.kicad_sch]
2024-05-15 KiCAD 8.0
    [M302.kicad_pcb, M302.kicad_sch, M302.sch]
2025-02-05 BOM reset
